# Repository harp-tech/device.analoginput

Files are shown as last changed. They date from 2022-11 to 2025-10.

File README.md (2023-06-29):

## Harp Analog Input

This device samples simultaneously up to 4 analog signals with 16 bits resolution, low noise and and analog input range of ±10 V for all channels.

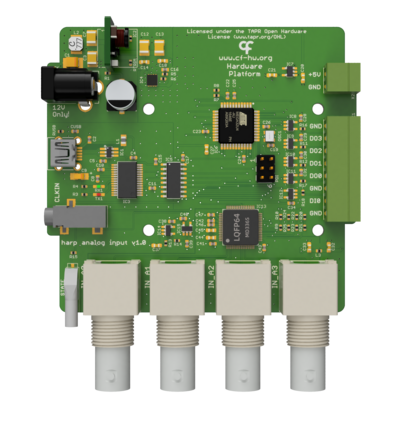
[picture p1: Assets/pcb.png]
harpanaloginput


### Key Features ###

* 4 ADC channels
* 16bit resolution with an input range of +-10V
* Simultaneous acquisition of all channels
* Threshold detection and event generation

### Connectivity ###

* 4 BNC connectors for analog input
* I/O connector for TTL signals

## Interface ##

The interface with the Harp board can be done through [Bonsai](https://bonsai-rx.org/)

## Licensing ##

Each subdirectory will contain a license or, possibly, a set of licenses if it involves both hardware and software.

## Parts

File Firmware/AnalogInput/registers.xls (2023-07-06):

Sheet: registers
Has event. | When | Type | Array | Array Len. | Register Name | Desciption | Mask Type | Value | Name | Desciption
no |  | U8 | no |  | START | Writing any value above ZERO will start the acquisition. ZERO will stop it. | bit | (1<<0) | START
yes | When a new sample is acquired | I16 | yes | 4 | ANALOG_INPUTS | Value of the analog inputs
yes | When DI0_CONF == DI0_SYNC and the input changes | U8 | no |  | DI0 | State of digital input 0 (DI0) | bit | (1<<0) | DI0
no |  | U8 | no |  | RESERVED0 | Reserved for future purposes
no |  | U8 | no |  | RESERVED00 | Contains the thresholds current status
no |  | U8 | no |  | RANGE_AND_INPUT_FILTER | Configures voltage range and bandwidth | mask | 0x17 | RANGE_AND_INPUT_FILTER
 |  |  |  |  |  |  | group_mask | 0x06 | 5V_1K5
 |  |  |  |  |  |  | group_mask | 0x05 | 5V_3K
 |  |  |  |  |  |  | group_mask | 0x04 | 5V_6K
 |  |  |  |  |  |  | group_mask | 0x03 | 5V_10K3
 |  |  |  |  |  |  | group_mask | 0x02 | 5V_13K7
 |  |  |  |  |  |  | group_mask | 0x01 | 5V_15K
 |  |  |  |  |  |  | group_mask | 0x16 | 10V_1K5
 |  |  |  |  |  |  | group_mask | 0x15 | 10V_3K
 |  |  |  |  |  |  | group_mask | 0x14 | 10V_6K
 |  |  |  |  |  |  | group_mask | 0x13 | 10V_11K9
 |  |  |  |  |  |  | group_mask | 0x12 | 10V_18K5
 |  |  |  |  |  |  | group_mask | 0x11 | 10V_22K
no |  | U8 | no |  | SAMPLE_FREQUENCY | Sample rate of analog conversions | mask | (3<<0) | SAMPLE_FREQUENCY
 |  |  |  |  |  |  | group_mask | 0x00 | 1KHZ
 |  |  |  |  |  |  | group_mask | 0x01 | 2KHZ
no |  | U8 | no |  | DI0_CONF | Configuration of the digital input 0 (DI0) | mask | (3<<0) | DI0_SEL
 |  |  |  |  |  |  | group_mask | (0<<0) | DI0_SYNC | Use as a pure digital input
 |  |  |  |  |  |  | group_mask | (1<<0) | DI0_RISE_START_ACQ | Start acquisition when rising edge and stop when falling edge
 |  |  |  |  |  |  | group_mask | (2<<0) | DI0_FALL_START_ACQ | Start acquisition when falling edge and stop when rising edge
 |  |  |  |  |  |  | group_mask | (3<<0) | DI0_RISE_CATCH_SAMPLE | Acquire a sample when a rising edge is detected
no |  | U8 | no |  | DO0_CONF | Configuration of the digital output 0 (DO0) | mask | (3<<0) | DO0_SEL
 |  |  |  |  |  |  | group_mask | (0<<0) | DO0_DIG | Use as a pure digital output like all the other digital outputs
 |  |  |  |  |  |  | group_mask | (1<<0) | DO0_TGL_EACH_SEC | Toggle each second when acquiring
 |  |  |  |  |  |  | group_mask | (2<<0) | DO0_PULSE | The digital output will be ONE during period specified by register DO0_PULSE
no |  | U8 | no |  | DO0_PULSE | Pulse for the digital output 0 (DO0) [1:250]
no |  | U8 | no |  | DO_SET | Set the digital outputs | bit | (1<<0) | DO0
no |  | U8 | no |  | DO_CLEAR | Clear the digital outputs | bit | (1<<1) | DO1
no |  | U8 | no |  | DO_TOGGLE | Toggle the digital outputs | bit | (1<<2) | DO2
yes | When the values where changed by a threshold filter | U8 | no |  | DO_WRITE | Writes to the digital outputs | bit | (1<<3) | DO3
 |  |  |  |  |  |  | bit | (1<<4) | DO0_CHANGED
 |  |  |  |  |  |  | bit | (1<<5) | DO1_CHANGED
 |  |  |  |  |  |  | bit | (1<<6) | DO2_CHANGED
 |  |  |  |  |  |  | bit | (1<<7) | DO3_CHANGED
no |  | U8 | no |  | RESERVED1 | Reserved for future purposes
no |  | U8 | no |  | RESERVED2 | Reserved for future purposes
no |  | U8 | no |  | TRIGGER_DESTINY | Configures where to send the acquisition trigger | mask | 0x07 | TRIG_TO_DO0
no |  | U8 | no |  | RESERVED3 | Reserved for future purposes | group_mask | (0<<0) | TRIG_TO_NONE
no |  | U8 | no |  | RESERVED4 | Reserved for future purposes | group_mask | (1<<0) | TRIG_TO_DO0
no |  | U8 | no |  | RESERVED5 | Reserved for future purposes | group_mask | (2<<0) | TRIG_TO_DO1
no |  | U8 | no |  | RESERVED6 | Reserved for future purposes | group_mask | (3<<0) | TRIG_TO_DO2
no |  | U8 | no |  | RESERVED7 | Reserved for future purposes | group_mask | (4<<0) | TRIG_TO_DO3
no |  | U8 | no |  | RESERVED8 | Reserved for future purposes
no |  | U8 | no |  | RESERVED9 | Reserved for future purposes
no |  | U8 | no |  | RESERVED10 | Reserved for future purposes
no |  | U8 | no |  | RESERVED11 | Reserved for future purposes
 |  | U8 | no |  | DO0_CH | Analog input channel used to feed filter of the threshold 0 | mask | (16<<0) | ANA_CH
 |  | U8 | no |  | DO1_CH | Analog input channel used to feed filter of the threshold 1 | group_mask | (0<<0) | ANA0 | Analog input channel 0
 |  | U8 | no |  | DO2_CH | Analog input channel used to feed filter of the threshold 2 | group_mask | (1<<0) | ANA1 | Analog input channel 1
 |  | U8 | no |  | DO3_CH | Analog input channel used to feed filter of the threshold 3 | group_mask | (2<<0) | ANA2 | Analog input channel 2
 |  | U8 | no |  | RESERVED12 |  | group_mask | (3<<0) | ANA3 | Analog input channel 3
 |  | U8 | no |  | RESERVED13 |  | group_mask | (8<<0) | NOT_USED | Threshold not used
 |  | U8 | no |  | RESERVED14
 |  | U8 | no |  | RESERVED15
 |  | I16 | no |  | DO0_TH_VALUE | Value to be compared
 |  | I16 | no |  | DO1_TH_VALUE
 |  | I16 | no |  | DO2_TH_VALUE
 |  | I16 | no |  | DO3_TH_VALUE
 |  | U8 | no |  | RESERVED17
 |  | U8 | no |  | RESERVED18
 |  | U8 | no |  | RESERVED19
 |  | U8 | no |  | RESERVED20
 |  | U16 | no |  | DO0_TH_UP_SAMPLES | Number of samples above the configured threshold to set the digital output
 |  | U16 | no |  | DO1_TH_UP_SAMPLES
 |  | U16 | no |  | DO2_TH_UP_SAMPLES
 |  | U16 | no |  | DO3_TH_UP_SAMPLES
 |  | U8 | no |  | RESERVED21
 |  | U8 | no |  | RESERVED22
 |  | U8 | no |  | RESERVED23
 |  | U8 | no |  | RESERVED24
 |  | U16 | no |  | DO0_TH_DOWN_SAMPLES | Number of samples bellow the configured threshold to set the digital output
 |  | U16 | no |  | DO1_TH_DOWN_SAMPLES
 |  | U16 | no |  | DO2_TH_DOWN_SAMPLES
 |  | U16 | no |  | DO3_TH_DOWN_SAMPLES
 |  | U8 | no |  | RESERVED25
 |  | U8 | no |  | RESERVED26
 |  | U8 | no |  | RESERVED27
 |  | U8 | no |  | RESERVED28
no |  | U8 | no |  | RESERVED29

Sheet: meta data
who am I: | 1236
firmware major version: | 1
firmware minor version: | 0
hardware major version: | 1
hardware minor version: | 0
assembly version: | 0
device name: | AnalogInput

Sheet: ios
Pin Name | PORT | Pin | Direction | Use Input | Out | Out default | Pull | Sense | Int. priority | Int. number | Desciption | Neg. Output
DI0 | PORTB | 0 | input |  |  |  | up | both_edges | low | 0 | Input DIO
DO0 | PORTA | 0 | output | yes | digital | 0 |  |  |  |  | Output DO0 | no
DO1 | PORTA | 1 | output | yes | digital | 0 |  |  |  |  | Output DO1 | no
DO2 | PORTA | 2 | output | yes | digital | 0 |  |  |  |  | Output DO2 | no
DO3 | PORTA | 3 | output | yes | digital | 0 |  |  |  |  | Output DO3 | no
CS_ADC | PORTC | 4 | output | yes | digital | 1 |  |  |  |  | Chip select | yes
CONVSTA | PORTC | 0 | output | yes | digital | 0 |  |  |  |  | Convert | no
CONVSTB | PORTC | 1 | output | yes | digital | 0 |  |  |  |  | Convert | no
MOSI | PORTC | 5 | output | no | digital | 0 |  |  |  |  | Serial data input | no
MISO | PORTC | 6 | input |  |  |  | up | both_edges | off | 0 | Serial data output
SCK | PORTC | 7 | output | no | digital | 0 |  |  |  |  | Serial data clock | no
RESET | PORTD | 0 | output | yes | digital | 0 |  |  |  |  | Reset | no
BUSY | PORTD | 1 | input |  |  |  | up | falling_edge | low | 0 | Busy
OS0 | PORTD | 2 | output | yes | digital | 0 |  |  |  |  | Oversampling bit 0 | no
OS1 | PORTD | 3 | output | no | digital | 1 |  |  |  |  | Oversampling bit 1 | no
OS2 | PORTD | 4 | output | no | digital | 1 |  |  |  |  | Oversampling bit 2 | no
RANGE | PORTA | 4 | output | yes | digital | 0 |  |  |  |  | Selects range 5 or 10V | no

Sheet: options
Array | Type | Array | Bits type | Direction | Use input | Pull | Sense | Int. priority | Int. number | Int. Mask | Out | Neg. Output
 |  |  |  | input | yes | up | both_edges | low | 0 |  | digital | yes
yes | U8 | yes | bit | output | no | down | rising_edge | med | 1 |  | wire_or | no
no | U16 | no | mask |  |  | tristate | falling_edge | high |  |  | wire_and
 | U32 |  | group_mask |  |  | busholder | low_level | off |  |  | wired_or_pull
 | U64 |  |  |  |  |  | no_interrupt |  |  |  | wired_and_pull
 | I8
 | I16
 | I32
 | I64
 | FLOAT

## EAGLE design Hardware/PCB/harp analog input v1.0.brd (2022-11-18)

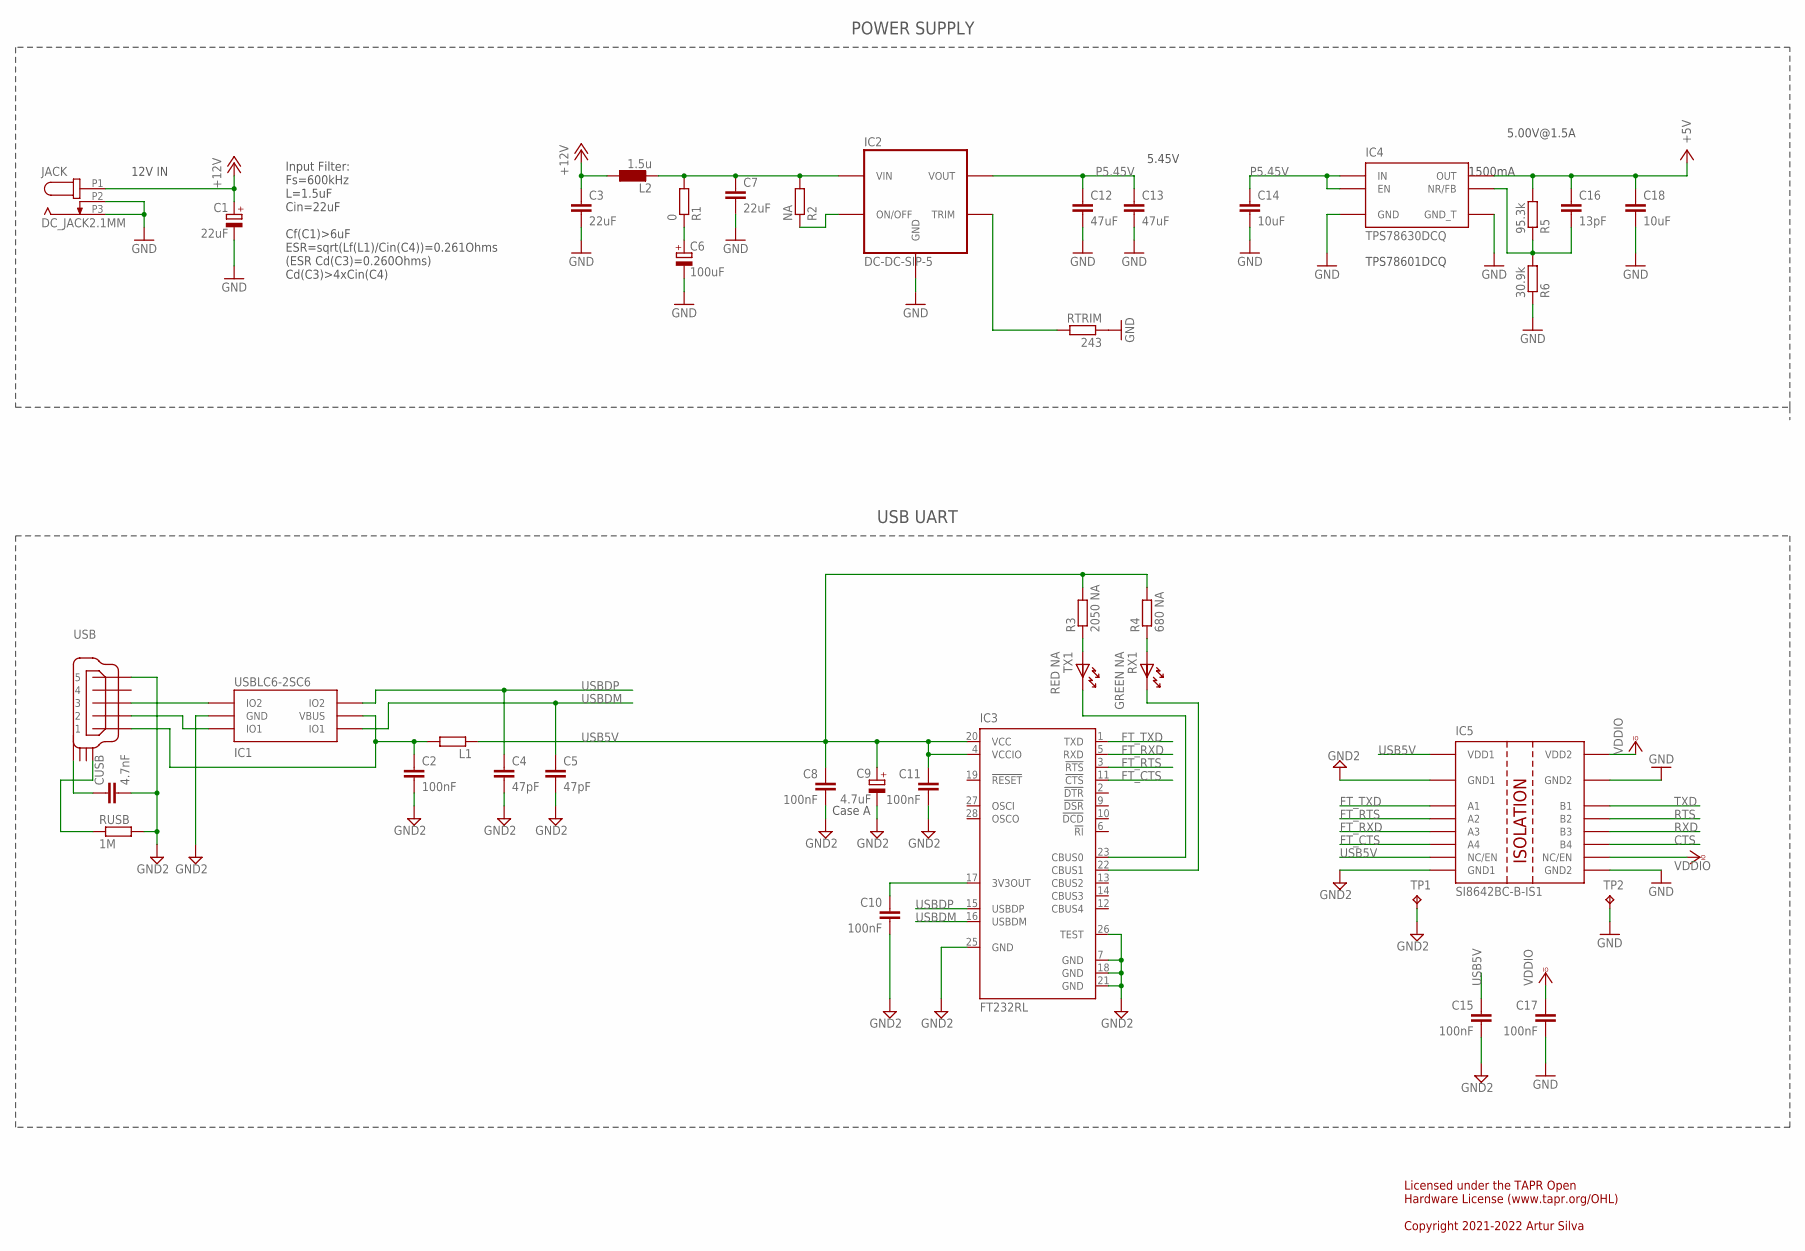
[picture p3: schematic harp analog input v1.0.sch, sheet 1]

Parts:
C1: 22uF; CAP_100UF_HAND
C2, C8, C10, C11, C15, C17: 100nF; C0402
C3, C7: 22uF; C1210
C4, C5: 47pF; C0402
C6: 100uF; PANASONIC_E
C9: 4.7uF; A/3216-18W
C12, C13: 47uF; C1210
C14, C18: 10uF; C0603
C16: 13pF; C0402
CUSB: 4.7nF; C0402
IC1: USBLC6-2SC6; SOT23-6L
IC2: DC-DC-SIP-5; SIP-5
IC3: FT232RL; SSOP28
IC4: TPS78630DCQ; SON-8
IC5: SI8642BC-B-IS1; NSOIC-16
JACK: DC_JACK2.1MM; DC_POWER_INPUT_2.1MM
L1: ???; R0805
L2: 1.5u; IND_LPS4012
R1: 0; R0402
R2: NA; R0402
R3: 2050 NA; R0402
R4: 680 NA; R0402
R5: 95.3k; R0402
R6: 30.9k; R0402
RTRIM: 243; R0402
RUSB: 1M; R0402
RX1: GREEN NA; LED_HAND
TP1, TP2: TPTP08SQ; TP08SQ
TX1: RED NA; LED_HAND
USB: USB_MINI_B; 240-0002-1

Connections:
3V3OUT: C10.1, IC3.17 (3V3OUT)
+5V: C16.1, C18.1, IC4.P3 (OUT), IC4.P4 (OUT), R5.2; also elsewhere on the board
+12V: C1.+, C3.1, JACK.P1 (1), L2.1
CTS: IC5.11 (B4); also elsewhere on the board
DCIN: C7.1, IC2.P2 (VIN), L2.2, R1.2, R2.2
FT_CTS: IC3.11 (!CTS), IC5.6 (A4)
FT_RTS: IC3.3 (!RTS), IC5.4 (A2)
FT_RXD: IC3.5 (RXD), IC5.5 (A3)
FT_TXD: IC3.1 (TXD), IC5.3 (A1)
GND: C1.-, C3.2, C6.-, C7.2, C12.2, C13.2, C14.2, C17.2, C18.2, IC2.P3 (GND), IC4.P6 (GND), IC4.P9 (GND_T), IC5.9 (GND2), IC5.15 (GND2), JACK.P2 (2), JACK.P3 (3), R6.1, RTRIM.1, TP2.TP; also elsewhere on the board
GND2: C2.2, C4.2, C5.2, C8.2, C9.-, C10.2, C11.2, C15.2, CUSB.2, IC1.P$2 (GND), IC3.7 (GND), IC3.18 (GND), IC3.21 (GND), IC3.25 (GND), IC3.26 (TEST), IC5.2 (GND1), IC5.8 (GND1), RUSB.2, TP1.TP, USB.P$5 (5)
unnamed: R4.1, RX1.A
unnamed: IC3.22 (CBUS1), RX1.K
unnamed: IC2.P5 (TRIM), RTRIM.2
unnamed: IC1.P$3 (IO2), USB.P$3 (3)
unnamed: CUSB.1, USB.SHIELD_4
unnamed: IC2.P1 (ON/OFF), R2.1
unnamed: C16.2, IC4.P5 (NR/FB), R5.1, R6.2
unnamed: C6.+, R1.1
unnamed: C2.1, IC1.P$5 (VBUS), L1.2, USB.P$1 (1)
unnamed: R3.1, TX1.A
unnamed: IC3.23 (CBUS0), TX1.K
unnamed: RUSB.1, USB.SHIELD_1
unnamed: IC1.P$1 (IO1), USB.P$2 (2)
P5.45V: C12.1, C13.1, C14.1, IC2.P4 (VOUT), IC4.P1 (IN), IC4.P2 (IN), IC4.P8 (EN)
RTS: IC5.13 (B2); also elsewhere on the board
RXD: IC5.12 (B3); also elsewhere on the board
TXD: IC5.14 (B1); also elsewhere on the board
USB5V: C8.1, C9.+, C11.1, C15.1, IC3.4 (VCCIO), IC3.20 (VCC), IC5.1 (VDD1), IC5.7 (NC/EN), L1.1, R3.2, R4.2
USBDM: C5.1, IC1.P$6 (IO1), IC3.16 (USBDM)
USBDP: C4.1, IC1.P$4 (IO2), IC3.15 (USBDP)
VCCIO: C17.1, IC5.10 (NC/EN), IC5.16 (VDD2); also elsewhere on the board

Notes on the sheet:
12V IN
5.45V
1500mA
TPS78601DCQ
5.00V@1.5A
Input Filter: Fs=600kHz L=1.5uF Cin=22uF Cf(C1)>6uF ESR=sqrt(Lf(L1)/Cin(C4))=0.261Ohms (ESR Cd(C3)=0.260Ohms) Cd(C3)>4xCin(C4)
Case A
USB UART
Licensed under the TAPR Open Hardware License (www.tapr.org/OHL) Copyright 2021-2022 Artur Silva
POWER SUPPLY

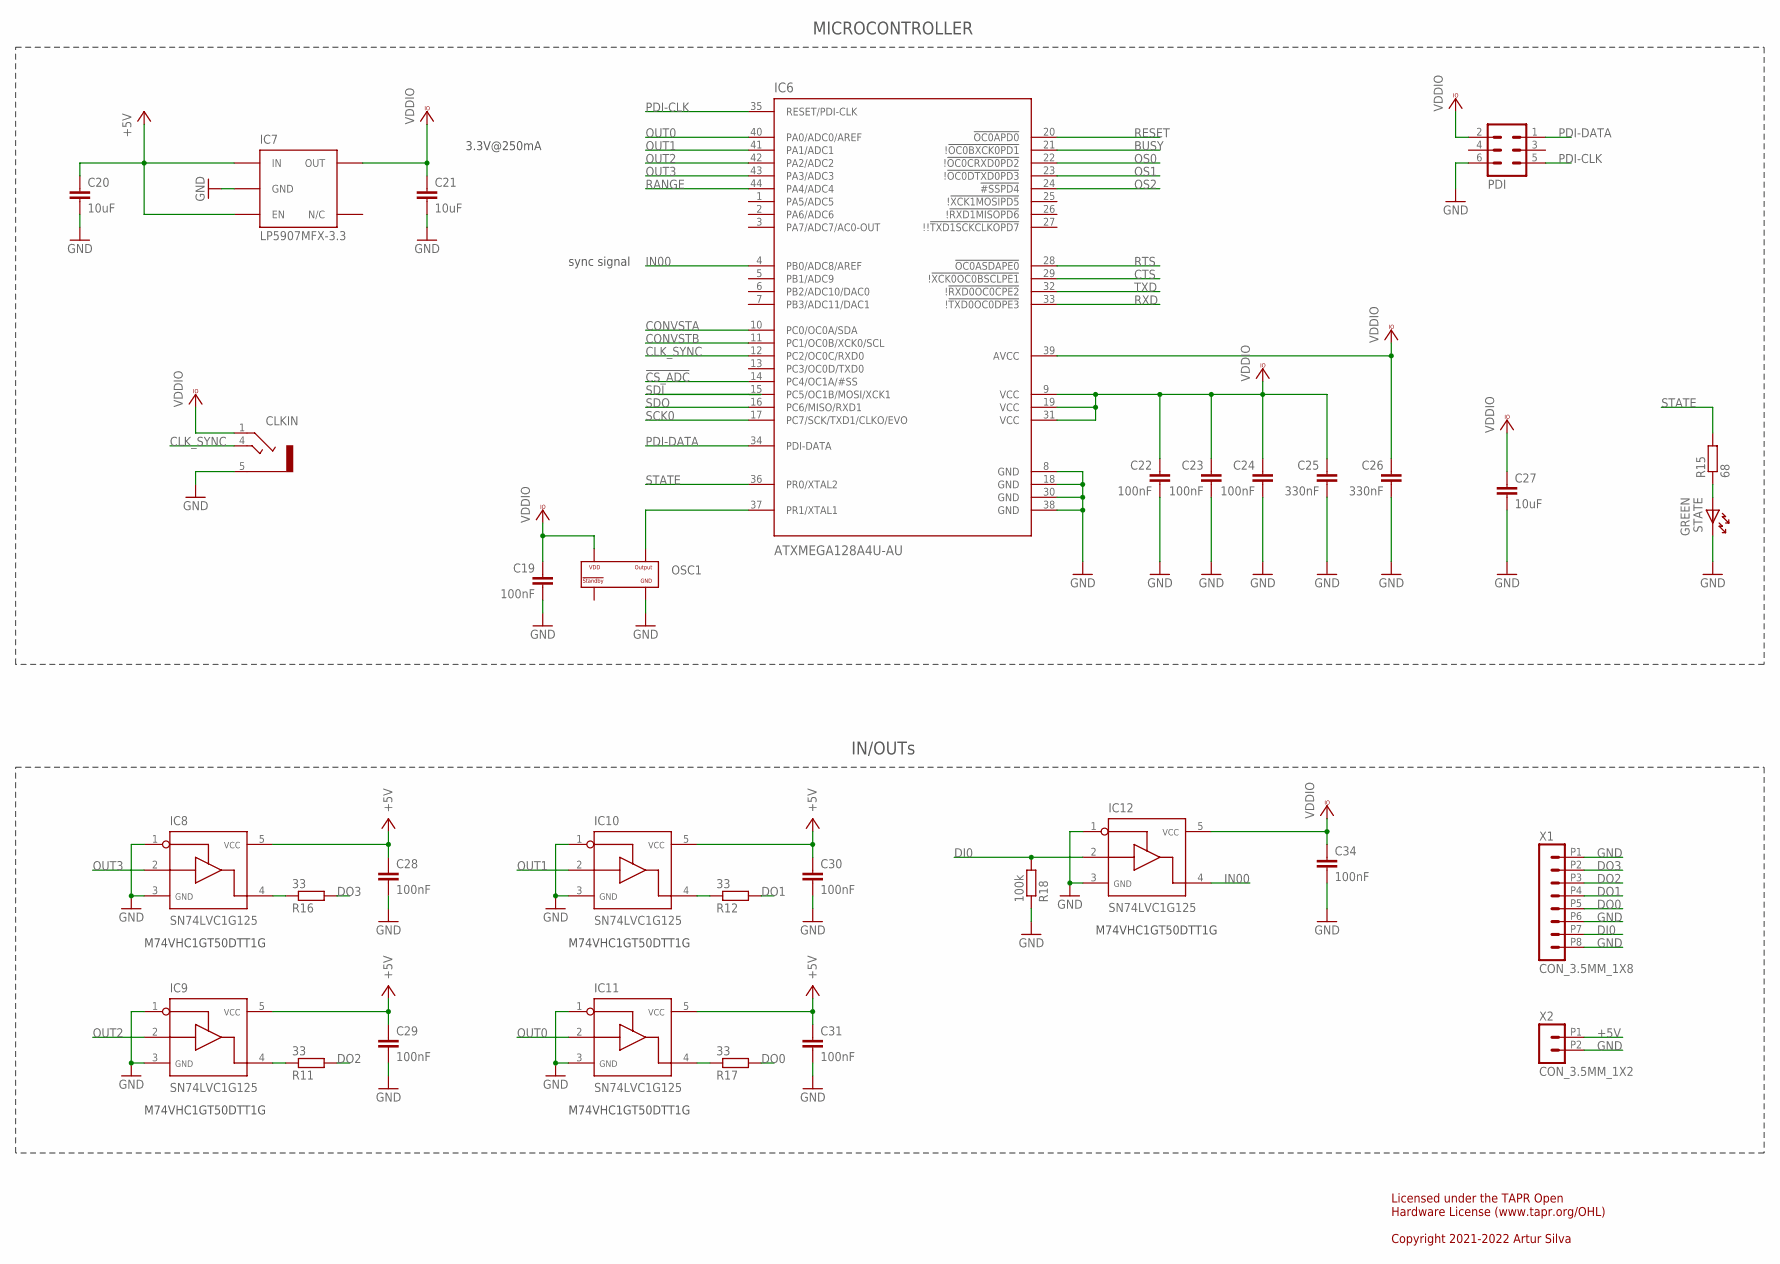
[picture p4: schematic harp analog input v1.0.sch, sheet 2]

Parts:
C19, C22, C23, C24, C28, C29, C30, C31, C34: 100nF; C0402
C20, C21, C27: 10uF; C0603
C25, C26: 330nF; C0402
CLKIN: STEREO_JACK; 35RASMT2BHNTRX
IC6: ATXMEGA128A4U-AU; QFP80P1200X1200X120-44N
IC7: LP5907MFX-3.3; TSOT23-5
IC8, IC9, IC10, IC11, IC12: SN74LVC1G125; SOT23-5
OSC1: OSCILLATOR; OSCILLATOR_3.2X2.5
PDI: MA03-2
R11, R12, R16, R17: 33; R0402
R15: 68; R0402
R18: 100k; R0402
STATE: GREEN; LED_HAND
X1: CON_3.5MM_1X8
X2: CON_3.5MM_1X2

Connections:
!CS_ADC: IC6.14 (PC4/OC1A/#SS); also elsewhere on the board
+5V: C20.1, C28.1, C29.1, C30.1, C31.1, IC7.1 (IN), IC7.3 (EN), IC8.5, IC9.5, IC10.5, IC11.5, X2.P1 (1); also elsewhere on the board
BUSY: IC6.21 (!!OC0BXCK0PD1); also elsewhere on the board
CLK_SYNC: CLKIN.4, IC6.12 (PC2/OC0C/RXD0)
CONVSTA: IC6.10 (PC0/OC0A/SDA); also elsewhere on the board
CONVSTB: IC6.11 (PC1/OC0B/XCK0/SCL); also elsewhere on the board
CTS: IC6.29 (!!XCK0OC0BSCLPE1); also elsewhere on the board
DI0: IC12.2, R18.2, X1.P7 (7)
DO0: R17.2, X1.P5 (5)
DO1: R12.2, X1.P4 (4)
DO2: R11.2, X1.P3 (3)
DO3: R16.2, X1.P2 (2)
GND: C19.2, C20.2, C21.2, C22.2, C23.2, C24.2, C25.2, C26.2, C27.2, C28.2, C29.2, C30.2, C31.2, C34.2, CLKIN.5, IC6.8 (GND), IC6.18 (GND), IC6.30 (GND), IC6.38 (GND), IC7.2 (GND), IC8.1, IC8.3, IC9.1, IC9.3, IC10.1, IC10.3, IC11.1, IC11.3, IC12.1, IC12.3, OSC1.P$2 (GND), PDI.6, R18.1, STATE.K, X1.P1 (1), X1.P6 (6), X1.P8 (8), X2.P2 (2); also elsewhere on the board
IN00: IC6.4 (PB0/ADC8/AREF), IC12.4
unnamed: IC9.4, R11.1
unnamed: IC10.4, R12.1
unnamed: IC11.4, R17.1
unnamed: IC8.4, R16.1
unnamed: R15.1, STATE.A
OS0: IC6.22 (!!OC0CRXD0PD2); also elsewhere on the board
OS1: IC6.23 (!!OC0DTXD0PD3); also elsewhere on the board
OS2: IC6.24 (!#SSPD4); also elsewhere on the board
OSC1: IC6.37 (PR1/XTAL1), OSC1.P$3 (OUTPUT)
OUT0: IC6.40 (PA0/ADC0/AREF), IC11.2
OUT1: IC6.41 (PA1/ADC1), IC10.2
OUT2: IC6.42 (PA2/ADC2), IC9.2
OUT3: IC6.43 (PA3/ADC3), IC8.2
PDI-CLK: IC6.35 (RESET/PDI-CLK), PDI.5
PDI-DATA: IC6.34 (PDI-DATA), PDI.1
RANGE: IC6.44 (PA4/ADC4); also elsewhere on the board
RESET: IC6.20 (!OC0APD0); also elsewhere on the board
RTS: IC6.28 (!OC0ASDAPE0); also elsewhere on the board
RXD: IC6.33 (!!TXD0OC0DPE3); also elsewhere on the board
SCK0: IC6.17 (PC7/SCK/TXD1/CLKO/EVO); also elsewhere on the board
SDI: IC6.15 (PC5/OC1B/MOSI/XCK1)
SDO: IC6.16 (PC6/MISO/RXD1); also elsewhere on the board
STATE: IC6.36 (PR0/XTAL2), R15.2
TXD: IC6.32 (!!RXD0OC0CPE2); also elsewhere on the board
VCCIO: C19.1, C21.1, C22.1, C23.1, C24.1, C25.1, C26.1, C27.1, C34.1, CLKIN.1, IC6.9 (VCC), IC6.19 (VCC), IC6.31 (VCC), IC6.39 (AVCC), IC7.5 (OUT), IC12.5, OSC1.P$4 (VDD), PDI.2; also elsewhere on the board

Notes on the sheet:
3.3V@250mA
sync signal
Licensed under the TAPR Open Hardware License (www.tapr.org/OHL) Copyright 2021-2022 Artur Silva
M74VHC1GT50DTT1G
MICROCONTROLLER
IN/OUTs

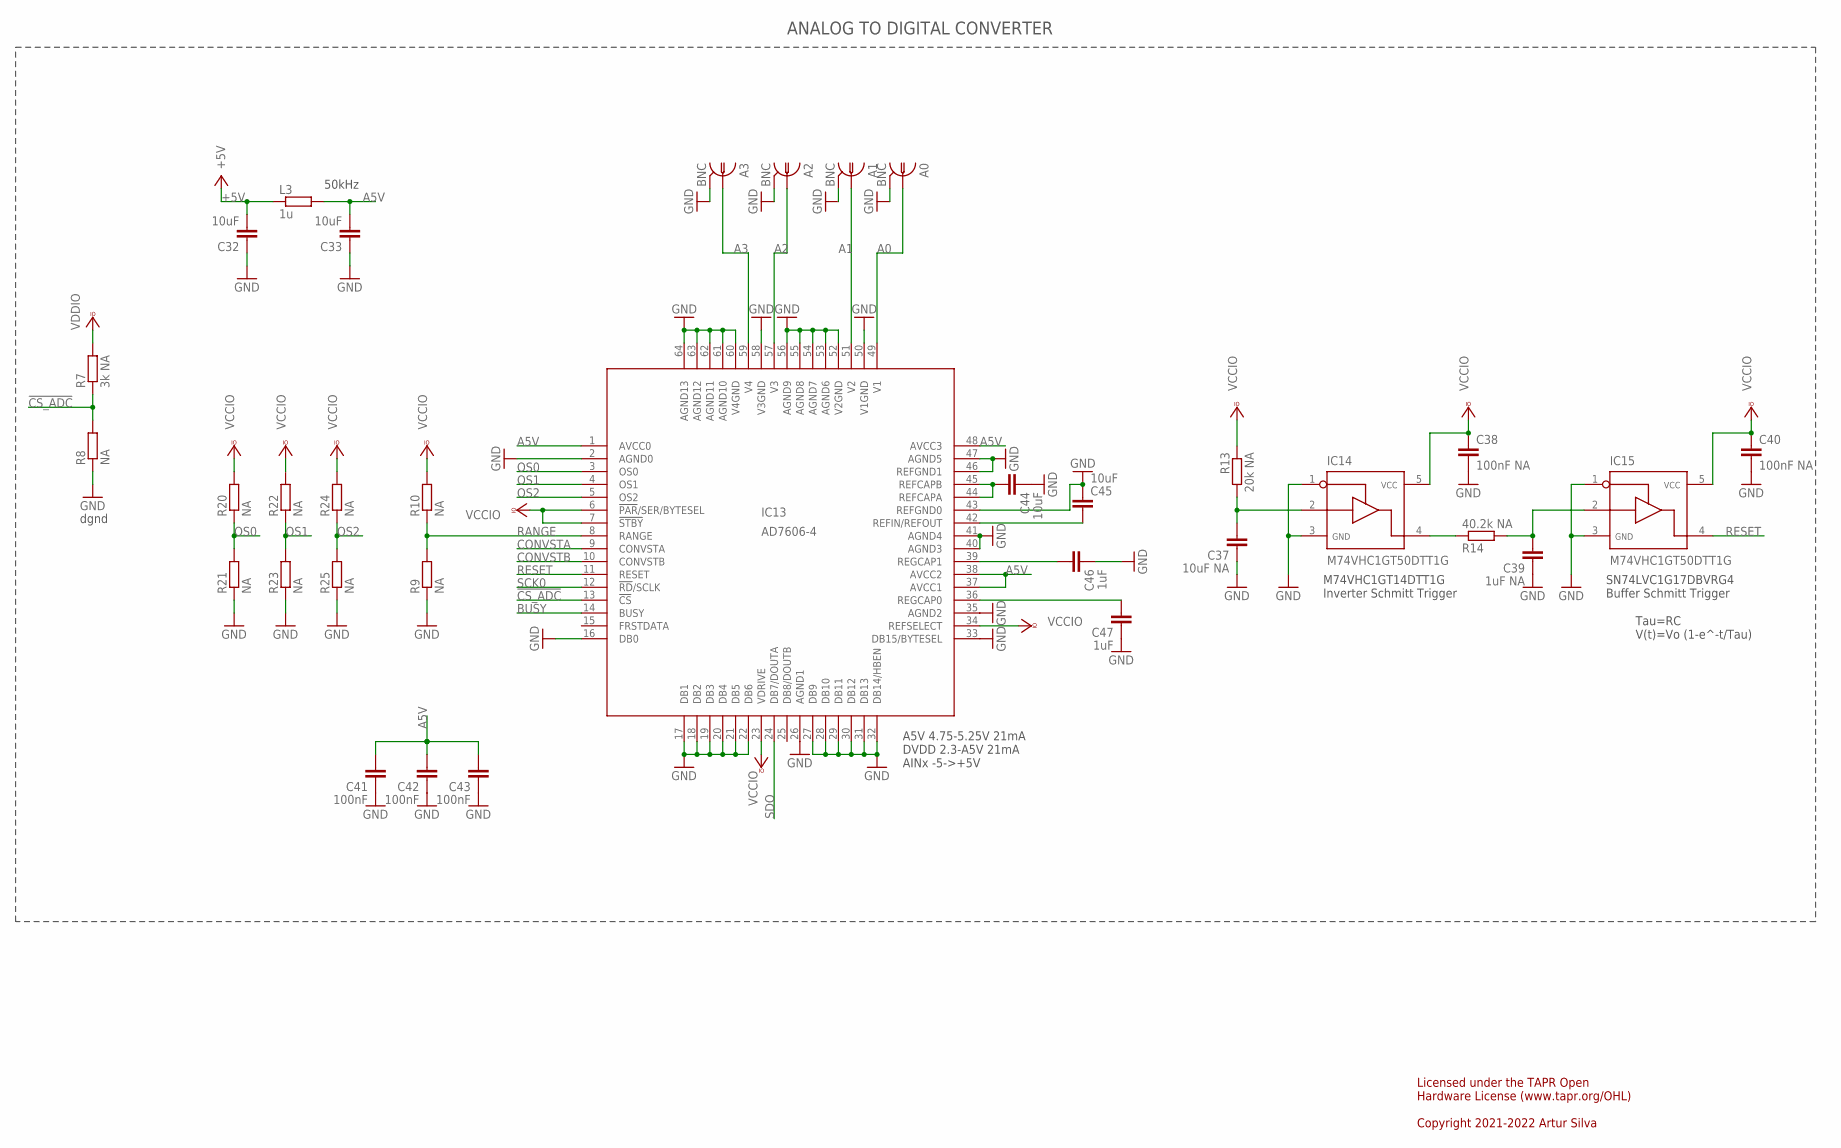
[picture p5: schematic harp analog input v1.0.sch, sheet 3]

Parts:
A0, A1, A2, A3: BNC; BNC_RA
C32, C33, C44, C45: 10uF; C0603
C37: 10uF NA; C0603
C38, C40: 100nF NA; C0402
C39: 1uF NA; C0402
C41, C42, C43: 100nF; C0402
C46, C47: 1uF; C0402
IC13: AD7606-4; LQFP-64
IC14, IC15: M74VHC1GT50DTT1G; SOT23-5
L3: 1u; R0402
R7: 3k NA; R0402
R8, R9, R10, R20, R21, R22, R23, R24, R25: NA; R0402
R13: 20k NA; R0402
R14: 40.2k NA; R0402

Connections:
!CS_ADC: IC13.13 (!CS), R7.1, R8.2; also elsewhere on the board
+5V: C32.2, L3.1; also elsewhere on the board
A0: A0.1, IC13.49 (V1)
A1: A1.1, IC13.51 (V2)
A2: A2.1, IC13.57 (V3)
A3: A3.1, IC13.59 (V4)
A5V: C33.2, C41.2, C42.2, C43.2, IC13.1 (AVCC0), IC13.37 (AVCC1), IC13.38 (AVCC2), IC13.48 (AVCC3), L3.2
BUSY: IC13.14 (BUSY); also elsewhere on the board
CONVSTA: IC13.9 (CONVSTA); also elsewhere on the board
CONVSTB: IC13.10 (CONVSTB); also elsewhere on the board
GND: A0.2, A1.2, A2.2, A3.2, C32.1, C33.1, C37.1, C38.2, C39.1, C40.2, C41.1, C42.1, C43.1, C44.1, C45.1, C46.1, C47.1, IC13.2 (AGND0), IC13.16 (DB0), IC13.17 (DB1), IC13.18 (DB2), IC13.19 (DB3), IC13.20 (DB4), IC13.21 (DB5), IC13.22 (DB6), IC13.26 (AGND1), IC13.27 (DB9), IC13.28 (DB10), IC13.29 (DB11), IC13.30 (DB12), IC13.31 (DB13), IC13.32 (DB14/HBEN), IC13.33 (DB15/BYTESEL), IC13.35 (AGND2), IC13.40 (AGND3), IC13.41 (AGND4), IC13.43 (REFGND0), IC13.46 (REFGND1), IC13.47 (AGND5), IC13.50 (V1GND), IC13.52 (V2GND), IC13.53 (AGND6), IC13.54 (AGND7), IC13.55 (AGND8), IC13.56 (AGND9), IC13.58 (V3GND), IC13.60 (V4GND), IC13.61 (AGND10), IC13.62 (AGND11), IC13.63 (AGND12), IC13.64 (AGND13), IC14.1, IC14.3, IC15.1, IC15.3, R8.1, R9.1, R21.1, R23.1, R25.1; also elsewhere on the board
unnamed: C47.2, IC13.36 (REGCAP0)
unnamed: C46.2, IC13.39 (REGCAP1)
unnamed: C45.2, IC13.42 (REFIN/REFOUT)
unnamed: C44.2, IC13.44 (REFCAPA), IC13.45 (REFCAPB)
unnamed: C37.2, IC14.2, R13.2
unnamed: IC14.4, R14.1
unnamed: C39.2, IC15.2, R14.2
OS0: IC13.3 (OS0), R20.1, R21.2; also elsewhere on the board
OS1: IC13.4 (OS1), R22.1, R23.2; also elsewhere on the board
OS2: IC13.5 (OS2), R24.1, R25.2; also elsewhere on the board
RANGE: IC13.8 (RANGE), R9.2, R10.1; also elsewhere on the board
RESET: IC13.11 (RESET), IC15.4; also elsewhere on the board
SCK0: IC13.12 (!RD!/SCLK); also elsewhere on the board
SDO: IC13.24 (DB7/DOUTA); also elsewhere on the board
VCCIO: C38.1, C40.1, IC13.6 (!PAR!/SER/BYTESEL), IC13.7 (!STBY), IC13.23 (VDRIVE), IC13.34 (REFSELECT), IC14.5, IC15.5, R7.2, R10.2, R13.1, R20.2, R22.2, R24.2; also elsewhere on the board

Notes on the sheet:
A5V 4.75-5.25V 21mA DVDD 2.3-A5V 21mA AINx -5->+5V
50kHz
M74VHC1GT14DTT1G Inverter Schmitt Trigger
SN74LVC1G17DBVRG4 Buffer Schmitt Trigger
Tau=RC V(t)=Vo (1-e^-t/Tau)
dgnd
Licensed under the TAPR Open Hardware License (www.tapr.org/OHL) Copyright 2021-2022 Artur Silva
ANALOG TO DIGITAL CONVERTER

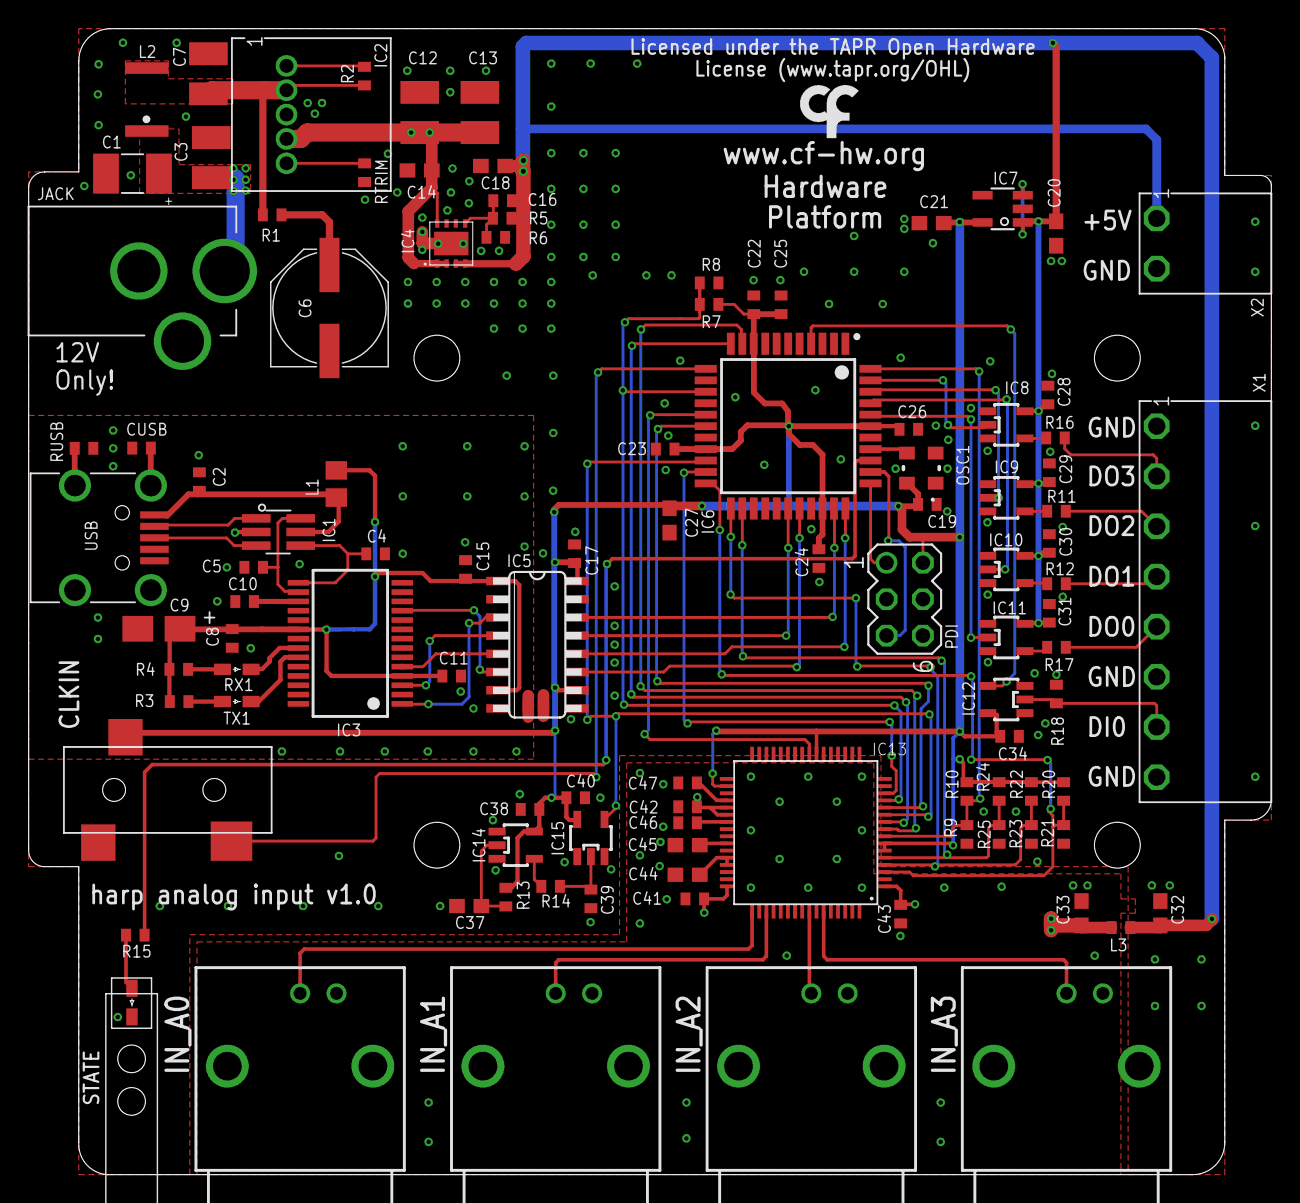
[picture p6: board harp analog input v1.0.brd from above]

Board: 2 copper layers, 86.8 x 80.0 mm, 109 parts (1 on the bottom side), 75 nets.

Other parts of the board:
U$2: LOGO_5
U$3: LED_PIPE_7513D2-L
U$4: LOGO_7

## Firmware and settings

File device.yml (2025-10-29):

%YAML 1.1
---
# yaml-language-server: $schema=https://harp-tech.org/draft-02/schema/device.json
device: AnalogInput
whoAmI: 1236
firmwareVersion: "1.3"
hardwareTargets: "1.0"
registers:
  AcquisitionState:
    address: 32
    access: Write
    type: U8
    maskType: EnableFlag
    description: Enables the data acquisition.
  AnalogData:
    address: 33
    type: S16
    length: 4
    access: Event
    description: Value from a single read of all ADC channels.
    payloadSpec:
      Channel0:
        offset: 0
      Channel1:
        offset: 1
      Channel2:
        offset: 2
      Channel3:
        offset: 3
  DigitalInputState:
    address: 34
    access: Event
    type: U8
    maskType: DigitalInputs
    description: State of the digital input pin 0.
  Reserved0: &ReservedReg
    address: 35
    access: Read
    visibility: private
    type: U8
    description: Reserved
  Reserved1:
    <<: *ReservedReg
    address: 36
  RangeAndFilter:
    address: 37
    access: Write
    type: U8
    maskType: RangeAndFilterConfig
    description: Sets the range and LowPass filter cutoff of the ADC.
  SamplingRate:
    address: 38
    access: Write
    type: U8
    maskType: SamplingRateMode
    description: Sets the sampling frequency of the ADC.
  DI0Trigger:
    address: 39
    access: Write
    type: U8
    maskType: TriggerConfig
    description: Configuration of the digital input pin 0.
  DO0Sync:
    address: 40
    access: Write
    type: U8
    maskType: SyncConfig
    description: Configuration of the digital output pin 0.
  DO0PulseWidth:
    address: 41
    access: Write
    type: U8
    minValue: 1
    maxValue: 250
    description: Pulse duration (ms) for the digital output pin 0. The pulse will only be emitted when DO0Sync == Pulse.
  DigitalOutputSet: &output
    address: 42
    type: U8
    access: Write
    maskType: DigitalOutputs
    description: Set the specified digital output lines.
  DigitalOutputClear:
    <<: *output
    address: 43
    description: Clear the specified digital output lines.
  DigitalOutputToggle:
    <<: *output
    address: 44
    description: Toggle the specified digital output lines
  DigitalOutputState:
    <<: *output
    address: 45
    access: [Write, Event]
    description: Write the state of all digital output lines. An event will be emitted when the value of any pin was changed by a threshold event.
  Reserved2:
    <<: *ReservedReg
    address: 46
  Reserved3:
    <<: *ReservedReg
    address: 47
  SyncOutput:
    address: 48
    access: Write
    type: U8
    maskType: StartSyncOutputTarget
    description: Digital output that will be set when acquisition starts.
  Reserved4:
    <<: *ReservedReg
    address: 49
  Reserved5:
    <<: *ReservedReg
    address: 50
  Reserved6:
    <<: *ReservedReg
    address: 51
  Reserved7:
    <<: *ReservedReg
    address: 52
  Reserved8:
    <<: *ReservedReg
    address: 53
  Reserved9:
    <<: *ReservedReg
    address: 54
  Reserved10:
    <<: *ReservedReg
    address: 55
  Reserved11:
    <<: *ReservedReg
    address: 56
  Reserved12:
    <<: *ReservedReg
    address: 57
  DO0TargetChannel: &targetchannel
    address: 58
    access: Write
    type: U8
    maskType: AdcChannel
    description: Target ADC channel that will be used to trigger a threshold event on DO0 pin.
  DO1TargetChannel:
    <<: *targetchannel
    address: 59
    description: Target ADC channel that will be used to trigger a threshold event on DO1 pin.
  DO2TargetChannel:
    <<: *targetchannel
    address: 60
    description: Target ADC channel that will be used to trigger a threshold event on DO2 pin.
  DO3TargetChannel:
    <<: *targetchannel
    address: 61
    description: Target ADC channel that will be used to trigger a threshold event on DO3 pin.
  Reserved13:
    <<: *ReservedReg
    address: 62
  Reserved14:
    <<: *ReservedReg
    address: 63
  Reserved15:
    <<: *ReservedReg
    address: 64
  Reserved16:
    <<: *ReservedReg
    address: 65
  DO0Threshold: &thresholdvalue
    address: 66
    access: Write
    type: S16
    description: Value used to threshold an ADC read, and trigger DO0 pin.
  DO1Threshold:
    <<: *thresholdvalue
    address: 67
    description: Value used to threshold an ADC read, and trigger DO1 pin.
  DO2Threshold:
    <<: *thresholdvalue
    address: 68
    description: Value used to threshold an ADC read, and trigger DO2 pin.
  DO3Threshold:
    <<: *thresholdvalue
    address: 69
    description: Value used to threshold an ADC read, and trigger DO3 pin.
  Reserved17:
    <<: *ReservedReg
    address: 70
  Reserved18:
    <<: *ReservedReg
    address: 71
  Reserved19:
    <<: *ReservedReg
    address: 72
  Reserved20:
    <<: *ReservedReg
    address: 73
  DO0TimeAboveThreshold: &bufferedthreshold
    address: 74
    access: Write
    type: U16
    defaultValue: 0
    description: Time (ms) above threshold value that is required to trigger a DO0 pin event.
  DO1TimeAboveThreshold:
    <<: *bufferedthreshold
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

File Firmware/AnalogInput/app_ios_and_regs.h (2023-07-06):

#ifndef _APP_IOS_AND_REGS_H_
#define _APP_IOS_AND_REGS_H_
#include "cpu.h"

void init_ios(void);
/************************************************************************/
/* Definition of input pins                                             */
/************************************************************************/
// DI0                    Description: Input DIO
// MISO                   Description: Serial data output
// BUSY                   Description: Busy

#define read_DI0 read_io(PORTB, 0)              // DI0
#define read_MISO read_io(PORTC, 6)             // MISO
#define read_BUSY read_io(PORTD, 1)             // BUSY

/************************************************************************/
/* Definition of output pins                                            */
/************************************************************************/
// DO0                    Description: Output DO0
// DO1                    Description: Output DO1
// DO2                    Description: Output DO2
// DO3                    Description: Output DO3
// CS_ADC                 Description: Chip select
// CONVSTA                Description: Convert
// CONVSTB                Description: Convert
// MOSI                   Description: Serial data input
// SCK                    Description: Serial data clock
// RESET                  Description: Reset
// OS0                    Description: Oversampling bit 0
// OS1                    Description: Oversampling bit 1
// OS2                    Description: Oversampling bit 2
// RANGE                  Description: Selects range 5 or 10V

/* DO0 */
#define set_DO0 set_io(PORTA, 0)
#define clr_DO0 clear_io(PORTA, 0)
#define tgl_DO0 toggle_io(PORTA, 0)
#define read_DO0 read_io(PORTA, 0)

/* DO1 */
#define set_DO1 set_io(PORTA, 1)
#define clr_DO1 clear_io(PORTA, 1)
#define tgl_DO1 toggle_io(PORTA, 1)
#define read_DO1 read_io(PORTA, 1)

/* DO2 */
#define set_DO2 set_io(PORTA, 2)
#define clr_DO2 clear_io(PORTA, 2)
#define tgl_DO2 toggle_io(PORTA, 2)
#define read_DO2 read_io(PORTA, 2)

/* DO3 */
#define set_DO3 set_io(PORTA, 3)
#define clr_DO3 clear_io(PORTA, 3)
#define tgl_DO3 toggle_io(PORTA, 3)
#define read_DO3 read_io(PORTA, 3)

/* CS_ADC */
#define set_CS_ADC clear_io(PORTC, 4)
#define clr_CS_ADC set_io(PORTC, 4)
#define tgl_CS_ADC toggle_io(PORTC, 4)
#define read_CS_ADC read_io(PORTC, 4)

/* CONVSTA */
#define set_CONVSTA set_io(PORTC, 0)
#define clr_CONVSTA clear_io(PORTC, 0)
#define tgl_CONVSTA toggle_io(PORTC, 0)
#define read_CONVSTA read_io(PORTC, 0)

/* CONVSTB */
#define set_CONVSTB set_io(PORTC, 1)
#define clr_CONVSTB clear_io(PORTC, 1)
#define tgl_CONVSTB toggle_io(PORTC, 1)
#define read_CONVSTB read_io(PORTC, 1)

/* MOSI */
#define set_MOSI set_io(PORTC, 5)
#define clr_MOSI clear_io(PORTC, 5)
#define tgl_MOSI toggle_io(PORTC, 5)
#define read_MOSI read_io(PORTC, 5)

/* SCK */
#define set_SCK set_io(PORTC, 7)
#define clr_SCK clear_io(PORTC, 7)
#define tgl_SCK toggle_io(PORTC, 7)
#define read_SCK read_io(PORTC, 7)

/* RESET */
#define set_RESET set_io(PORTD, 0)
#define clr_RESET clear_io(PORTD, 0)
#define tgl_RESET toggle_io(PORTD, 0)
#define read_RESET read_io(PORTD, 0)

/* OS0 */
#define set_OS0 set_io(PORTD, 2)
#define clr_OS0 clear_io(PORTD, 2)
#define tgl_OS0 toggle_io(PORTD, 2)
#define read_OS0 read_io(PORTD, 2)

/* OS1 */
#define set_OS1 set_io(PORTD, 3)
#define clr_OS1 clear_io(PORTD, 3)
#define tgl_OS1 toggle_io(PORTD, 3)
#define read_OS1 read_io(PORTD, 3)

/* OS2 */
#define set_OS2 set_io(PORTD, 4)
#define clr_OS2 clear_io(PORTD, 4)
#define tgl_OS2 toggle_io(PORTD, 4)
#define read_OS2 read_io(PORTD, 4)

/* RANGE */
#define set_RANGE set_io(PORTA, 4)
#define clr_RANGE clear_io(PORTA, 4)
#define tgl_RANGE toggle_io(PORTA, 4)
#define read_RANGE read_io(PORTA, 4)


/************************************************************************/
/* Registers' structure                                                 */
/************************************************************************/
typedef struct
{
	uint8_t REG_START;
	int16_t REG_ANALOG_INPUTS[4];
	uint8_t REG_DI0;
	uint8_t REG_RESERVED0;
	uint8_t REG_RESERVED00;
	uint8_t REG_RANGE_AND_INPUT_FILTER;
	uint8_t REG_SAMPLE_FREQUENCY;
	uint8_t REG_DI0_CONF;
	uint8_t REG_DO0_CONF;
	uint8_t REG_DO0_PULSE;
	uint8_t REG_DO_SET;
	uint8_t REG_DO_CLEAR;
	uint8_t REG_DO_TOGGLE;
	uint8_t REG_DO_WRITE;
	uint8_t REG_RESERVED1;
	uint8_t REG_RESERVED2;
	uint8_t REG_TRIGGER_DESTINY;
	uint8_t REG_RESERVED3;
	uint8_t REG_RESERVED4;
	uint8_t REG_RESERVED5;
	uint8_t REG_RESERVED6;
	uint8_t REG_RESERVED7;
	uint8_t REG_RESERVED8;
	uint8_t REG_RESERVED9;
	uint8_t REG_RESERVED10;
	uint8_t REG_RESERVED11;
	uint8_t REG_DO0_CH;
	uint8_t REG_DO1_CH;
	uint8_t REG_DO2_CH;
	uint8_t REG_DO3_CH;
	uint8_t REG_RESERVED12;
	uint8_t REG_RESERVED13;
	uint8_t REG_RESERVED14;
	uint8_t REG_RESERVED15;
	int16_t REG_DO0_TH_VALUE;
	int16_t REG_DO1_TH_VALUE;
	int16_t REG_DO2_TH_VALUE;
	int16_t REG_DO3_TH_VALUE;
	uint8_t REG_RESERVED17;
	uint8_t REG_RESERVED18;
	uint8_t REG_RESERVED19;
	uint8_t REG_RESERVED20;
	uint16_t REG_DO0_TH_UP_SAMPLES;
	uint16_t REG_DO1_TH_UP_SAMPLES;
	uint16_t REG_DO2_TH_UP_SAMPLES;
	uint16_t REG_DO3_TH_UP_SAMPLES;
	uint8_t REG_RESERVED21;
	uint8_t REG_RESERVED22;
	uint8_t REG_RESERVED23;
	uint8_t REG_RESERVED24;
	uint16_t REG_DO0_TH_DOWN_SAMPLES;
	uint16_t REG_DO1_TH_DOWN_SAMPLES;
	uint16_t REG_DO2_TH_DOWN_SAMPLES;
	uint16_t REG_DO3_TH_DOWN_SAMPLES;
	uint8_t REG_RESERVED25;
	uint8_t REG_RESERVED26;
	uint8_t REG_RESERVED27;
	uint8_t REG_RESERVED28;
	uint8_t REG_RESERVED29;
} AppRegs;
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

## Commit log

2021-12-15 Create PCB folder and added license files
2021-12-15 Added PCB design files
    [harp analog input v1.0.brd, harp analog input v1.0.sch]
2021-12-20 Re-organized DO alignment from left (DO0) to right (DO3)
    [harp analog input v1.0.brd, harp analog input v1.0.sch]
2021-12-20 Correct minor DRC and net labelling from merge
    [harp analog input v1.0.brd, harp analog input v1.0.sch]
2022-04-12 Added first firmware files.
    [registers.xls]
2022-04-12 Implemented all firmware features except the digital outputs.
    [registers.xls]
2022-11-18 Add CONVST pin/swap CS_ADC
    To allow for future higher speed acquisitions
    [harp analog input v1.0.brd, harp analog input v1.0.sch]
2023-04-17 Add first draft of device schema
2023-04-17 Add generated Device classes
2023-04-19 Improve schema consistency with device.loadcells
2023-05-03 Add PCB image
2023-05-15 Resize PCB image
2023-05-20 Renamed pin CONVST to CONVSTA
    [registers.xls]
2023-05-20 Fix Digital Output pins
    [registers.xls]
2023-06-02 Update Device classes to new schema
2023-06-02 Update `Device` classes to new schema
2023-06-07 Improve schema for consistency with Device.LoadCells
2023-06-28 Update ADC filter mask values
2023-07-03 Changed RESET line to push-pull.
    [registers.xls]
2023-07-03 Removed catch sample on the falling edge.
2023-07-04 Removed catch sample on the falling edge from schema.
2023-08-19 Move folder and rename licenses
    [harp analog input v1.0.brd, harp analog input v1.0.sch]
2024-11-09 Update package metadata to embed device metadata
2024-11-10 Favor harp-tech as source of device schema

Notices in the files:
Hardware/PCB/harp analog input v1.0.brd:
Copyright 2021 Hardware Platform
